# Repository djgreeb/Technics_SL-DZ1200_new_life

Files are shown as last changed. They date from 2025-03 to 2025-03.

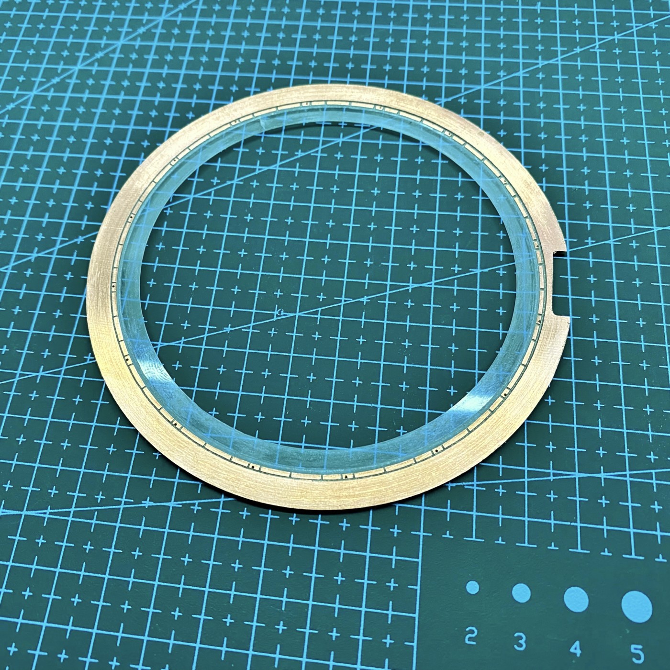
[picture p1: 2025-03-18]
Photo/IMG_2256.jpg

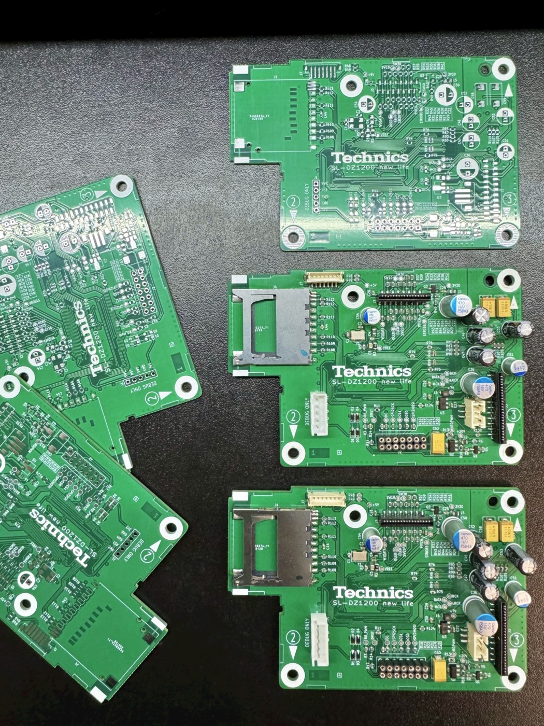
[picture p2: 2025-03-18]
Photo/IMG_4501.jpg

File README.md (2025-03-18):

# Technics_SL-DZ1200_new_life
 Technics, creating a new motherboard and display module.

This is a project to bring back to life the Technics SL-DZ1200 DJ player.

A new motherboard has been developed, based on the STM32F429 microcontroller. A new display module based on two OLED displays with a high frame refresh rate.

Added support for large capacity SD cards (64GB tested), support for playlists imported from Rekordbox, playback of wav files 16bit 44.1kHz only.

Display static and dynamic waveform, 8 hotspots, loop, slip loop, beat jump.

Digital SPDIF output is supported.

In addition to replacing the motherboard, it is necessary to modify the control panel boards and replace the display module.

Technics SL-DZ1200 new life. Comparison of sound and construction with the original deck:

https://youtu.be/YNCWHuYRNV8?si=jEZ1Wb_wVn2iVH1T

Other videos:

https://youtube.com/shorts/xwd6WtisLp0?si=1c5YiPtq2MnMOLq1

https://youtube.com/shorts/Ao05V8m91X4?si=t5FqrDS9XYP-LJhe

https://youtube.com/shorts/iWsxXxv2L6M?si=lasyaPYv3nFeNMoB

https://youtube.com/shorts/TOsjFpwztxs?si=jLOTwwjx0vi9ndan

    //	ver. 0.10
    //		- 64MB SDRAM
    //		- 2 OLED displays
    // 		- added scratch track
    //	ver. 0.21
    //		- project ported to new pcb
    //		- configured to work with the new DAC and SPDIF transmitter
    //		- most peripherals initialized
    //	ver. 0.23
    //		- most peripherals initialized
    //	ver. 0.25
    //		- TIM8 bug fixed. Missing a line: HAL_TIM_OnePulse_Init(&htim8, TIM_OPMODE_SINGLE) != HAL_OK)
    //	ver. 0.26
    //		- minor fixes
    //	ver. 0.27
    //		- split into separate *.h files
    //		- oled driver optimization
    //	ver. 0.31
    //		- added uart
    //		- added rgb leds function
    //		- added HD74HC164P LEDs
    //		- oled driver optimization
    //		- unused libraries cleaned up
    //	ver. 0.32
    //		- added adc process
    //		- TIM1 change config 333Hz->10KHz
    //	ver. 0.33
    //		- changed OLDEs configuration
    //		- added uart commands
    //		- LEDS_LOAD prc for HD74HC164P moved to audio handler 
    //	ver. 0.34
    //		- TIM1 change config 10KHz->3333Hz
    //		- added buttons prc
    //	ver. 0.35
    //		- minor fixes
    //	ver. 0.36
    //		- change motor GPIO initial state
    //	ver. 0.37
    //		- minor fixes
    //	ver. 0.38
    //		- add WFORMDYNAMIC reading prc
    //	ver. 0.41
    //		- minor fixes
    //	ver. 0.42
    //		- added rekordbox parser
    //	ver. 0.43
    //		- add blinking pads
    //	ver. 0.44
    //		- minor fixes
    //	ver. 0.47
    //		- added test sdram
    //		- added uart status messages
    //	ver. 0.49
    //		- added support use_lfn in fatfs
    //		- minor fixes
    //	ver. 0.51
    //		- improved SDRAM test
    //		- added fw version register to main.c
    //	ver. 0.53
    //		- minor fixes
    //		- changed the size of the heap and stack by 2X. Now Stack_Size 0x1000; Heap_Size 0x800;
    //	ver. 0.57
    //		- improved OLED library
    //		- rekordbox parser optimized
    //	ver. 0.61
    //		- improved OLED library
    //		- improved track loading process
    //	ver. 0.63
    //		- added optimization waveforms with color coefficient
    //	ver. 0.67
    //		- rekordbox parser improved
    //	ver. 0.68
    //		- fixed drawing of static waveform
    //	ver. 0.69
    //		- minor fixes
    //	ver. 0.70
    //		- CDJ900 font added
    //		- minor fixes
    //		- added pitch calculation
    //	ver. 0.71
    //		- added gui_generation.h
    //	ver. 0.74
    //		- minor fixes
    //	ver. 0.77
    //		- improved DrawMinuteMarkers()
    //		- added ShowTempo()
    //	ver. 0.81
    //		- removed initialization of SDRAM area from the scatter file, which significantly speeded up system startup
    //		- added mini sdram test
    //		- added ShowBPM()
    //	ver. 0.85
    //		- changed SDRAM parameter SdramTiming.WriteRecoveryTime = 4;			//2	//4 
    //		- changed adc pitch aproximation
    //		- added adc pitch hysteresis 
    //		- added DDM speed regulation
    //		- changed audio resampling coeff: optimal 32x, 4-point, 3rd-order optimal
    //		- improved and optimized audio resampling algorithm
    //	ver. 0.87
    //		- regenerated code in CubeMX
    //		- added encoder and timecode handlers
    //	ver. 0.89
    //		- added timecode encoder in code handler
    //	ver. 0.90
    //		- minor fixes
    //	ver. 0.92
    //		- fixed oled ram select
    //	ver. 0.93
    //		- added ROOT DISPLAY
    //	ver. 0.97
    //		- improved BORWSER functions
    //	ver. 0.98
    //		- added SD cars remove-insert handler
    //	ver. 0.99 
    //		- improved OLED_Putc function for outputting cut characters
    //	ver. 1.00 
    //		- fixed gui bug
    //	ver. 1.03 
    //		- fixed gui bug (increased size Stack_Size 0x1000, Heap_Size 0x800)
    //		- improved waveform code
    //	ver. 1.05
    //		- FontCDJ900 minor fixes
    //		- improved gui
    //		- added SD card symbol 
    //	ver. 1.07
    //		- added beatjump with calculate jump distantion
    //		- added hot cues a, b, c
    //	ver. 1.11
    //		- improved gui 
    //		- add browser animation
    //		- add 8 HOT CUES and PADS color from *.EXT file

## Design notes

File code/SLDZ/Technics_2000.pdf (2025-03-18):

## Technics_2000 Project Configuration Report

# 1. Description

## 1.1. Project

Project Name | Technics_2000
Board Name | Technics_2000
Generated with: | STM32CubeMX 4.22.0
Date | 04/03/2024

## 1.2. MCU

MCU Series | STM32F4
MCU Line | STM32F429/439
MCU name | STM32F429ZITx
MCU Package | LQFP144
MCU Pin number | 144

# 2. Pinout Configuration

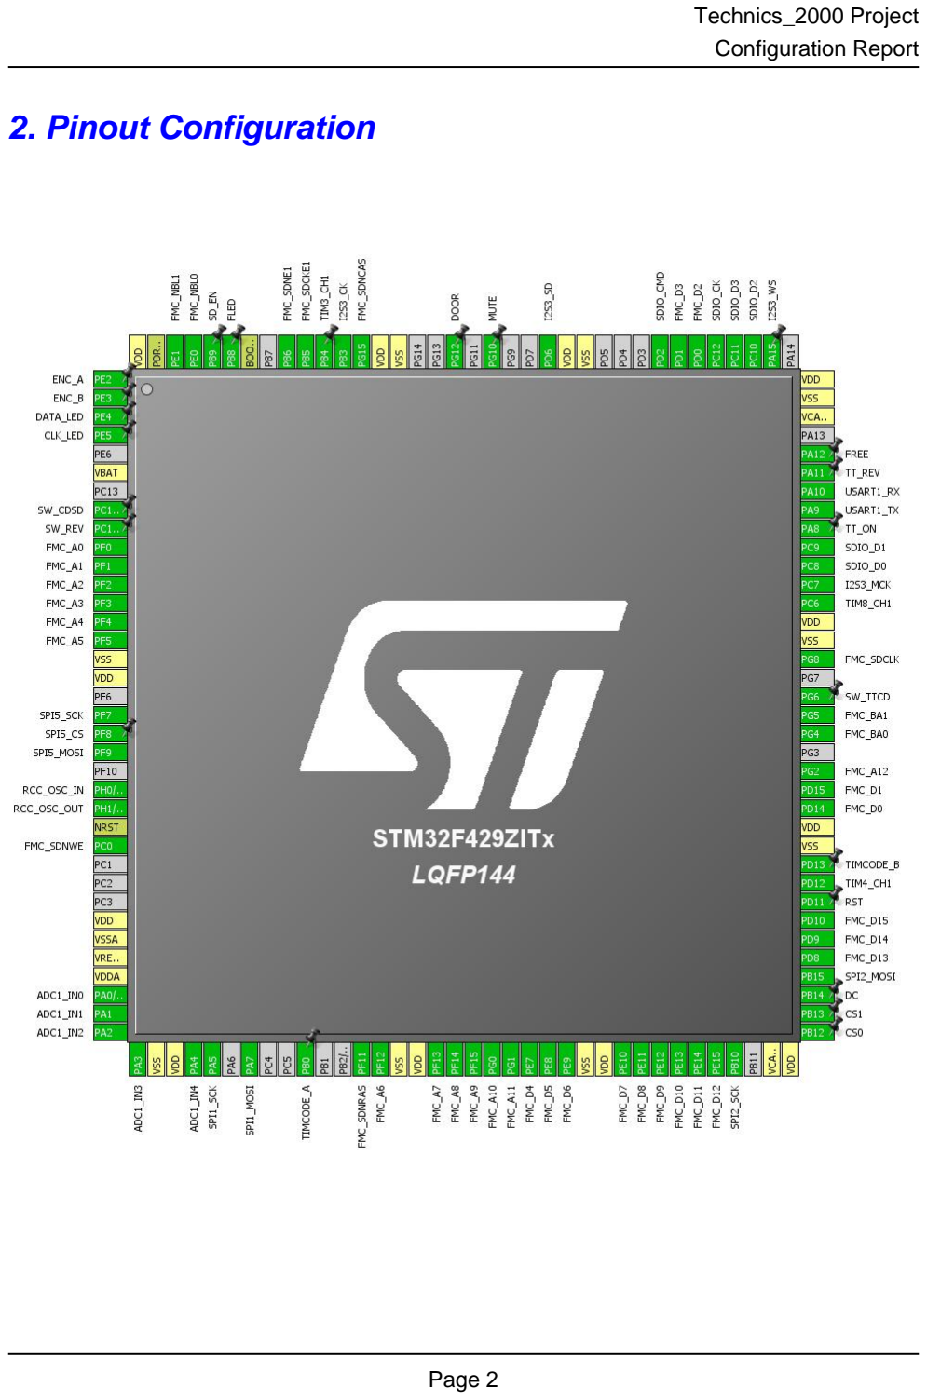
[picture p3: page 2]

# 3. Pins Configuration

Pin Number LQFP144 | Pin Name (function after reset) | Pin Type | Alternate Function(s) | Label
1 | PE2 | I/O | GPIO_EXTI2 | ENC_A
2 | PE3 * | I/O | GPIO_Input | ENC_B
3 | PE4 * | I/O | GPIO_Output | DATA_LED
4 | PE5 * | I/O | GPIO_Output | CLK_LED
6 | VBAT | Power
8 | PC14/OSC32_IN * | I/O | GPIO_Input | SW_CDSD
9 | PC15/OSC32_OUT * | I/O | GPIO_Input | SW_REV
10 | PF0 | I/O | FMC_A0
11 | PF1 | I/O | FMC_A1
12 | PF2 | I/O | FMC_A2
13 | PF3 | I/O | FMC_A3
14 | PF4 | I/O | FMC_A4
15 | PF5 | I/O | FMC_A5
16 | VSS | Power
17 | VDD | Power
19 | PF7 | I/O | SPI5_SCK
20 | PF8 * | I/O | GPIO_Output | SPI5_CS
21 | PF9 | I/O | SPI5_MOSI
23 | PH0/OSC_IN | I/O | RCC_OSC_IN
24 | PH1/OSC_OUT | I/O | RCC_OSC_OUT
25 | NRST | Reset
26 | PC0 | I/O | FMC_SDNWE
30 | VDD | Power
31 | VSSA | Power
32 | VREF+ | Power
33 | VDDA | Power
34 | PA0/WKUP | I/O | ADC1_IN0
35 | PA1 | I/O | ADC1_IN1
36 | PA2 | I/O | ADC1_IN2
37 | PA3 | I/O | ADC1_IN3
38 | VSS | Power
39 | VDD | Power
40 | PA4 | I/O | ADC1_IN4
41 | PA5 | I/O | SPI1_SCK
43 | PA7 | I/O | SPI1_MOSI
46 | PB0 | I/O | GPIO_EXTI0 | TIMCODE_A

Pin Number LQFP144 | Pin Name (function after reset) | Pin Type | Alternate Function(s) | Label
49 | PF11 | I/O | FMC_SDNRAS
50 | PF12 | I/O | FMC_A6
51 | VSS | Power
52 | VDD | Power
53 | PF13 | I/O | FMC_A7
54 | PF14 | I/O | FMC_A8
55 | PF15 | I/O | FMC_A9
56 | PG0 | I/O | FMC_A10
57 | PG1 | I/O | FMC_A11
58 | PE7 | I/O | FMC_D4
59 | PE8 | I/O | FMC_D5
60 | PE9 | I/O | FMC_D6
61 | VSS | Power
62 | VDD | Power
63 | PE10 | I/O | FMC_D7
64 | PE11 | I/O | FMC_D8
65 | PE12 | I/O | FMC_D9
66 | PE13 | I/O | FMC_D10
67 | PE14 | I/O | FMC_D11
68 | PE15 | I/O | FMC_D12
69 | PB10 | I/O | SPI2_SCK
71 | VCAP_1 | Power
72 | VDD | Power
73 | PB12 * | I/O | GPIO_Output | CS0
74 | PB13 * | I/O | GPIO_Output | CS1
75 | PB14 * | I/O | GPIO_Output | DC
76 | PB15 | I/O | SPI2_MOSI
77 | PD8 | I/O | FMC_D13
78 | PD9 | I/O | FMC_D14
79 | PD10 | I/O | FMC_D15
80 | PD11 * | I/O | GPIO_Output | RST
81 | PD12 | I/O | TIM4_CH1
82 | PD13 * | I/O | GPIO_Input | TIMCODE_B
83 | VSS | Power
84 | VDD | Power
85 | PD14 | I/O | FMC_D0
86 | PD15 | I/O | FMC_D1
87 | PG2 | I/O | FMC_A12
89 | PG4 | I/O | FMC_BA0

Pin Number LQFP144 | Pin Name (function after reset) | Pin Type | Alternate Function(s) | Label
90 | PG5 | I/O | FMC_BA1
91 | PG6 * | I/O | GPIO_Input | SW_TTCD
93 | PG8 | I/O | FMC_SDCLK
94 | VSS | Power
95 | VDD | Power
96 | PC6 | I/O | TIM8_CH1
97 | PC7 | I/O | I2S3_MCK
98 | PC8 | I/O | SDIO_D0
99 | PC9 | I/O | SDIO_D1
100 | PA8 * | I/O | GPIO_Output | TT_ON
101 | PA9 | I/O | USART1_TX
102 | PA10 | I/O | USART1_RX
103 | PA11 * | I/O | GPIO_Output | TT_REV
104 | PA12 * | I/O | GPIO_Output | FREE
106 | VCAP_2 | Power
107 | VSS | Power
108 | VDD | Power
110 | PA15 | I/O | I2S3_WS
111 | PC10 | I/O | SDIO_D2
112 | PC11 | I/O | SDIO_D3
113 | PC12 | I/O | SDIO_CK
114 | PD0 | I/O | FMC_D2
115 | PD1 | I/O | FMC_D3
116 | PD2 | I/O | SDIO_CMD
120 | VSS | Power
121 | VDD | Power
122 | PD6 | I/O | I2S3_SD
125 | PG10 * | I/O | GPIO_Output | MUTE
127 | PG12 * | I/O | GPIO_Input | DOOR
130 | VSS | Power
131 | VDD | Power
132 | PG15 | I/O | FMC_SDNCAS
133 | PB3 | I/O | I2S3_CK
134 | PB4 | I/O | TIM3_CH1
135 | PB5 | I/O | FMC_SDCKE1
136 | PB6 | I/O | FMC_SDNE1
138 | BOOT0 | Boot
139 | PB8 * | I/O | GPIO_Output | FLED
140 | PB9 * | I/O | GPIO_Input | SD_EN

Pin Number LQFP144 | Pin Name (function after reset) | Pin Type | Alternate Function(s) | Label
141 | PE0 | I/O | FMC_NBL0
142 | PE1 | I/O | FMC_NBL1
143 | PDR_ON | Reset
144 | VDD | Power

## * The pin is affected with an I/O function

# 4. Clock Tree Configuration

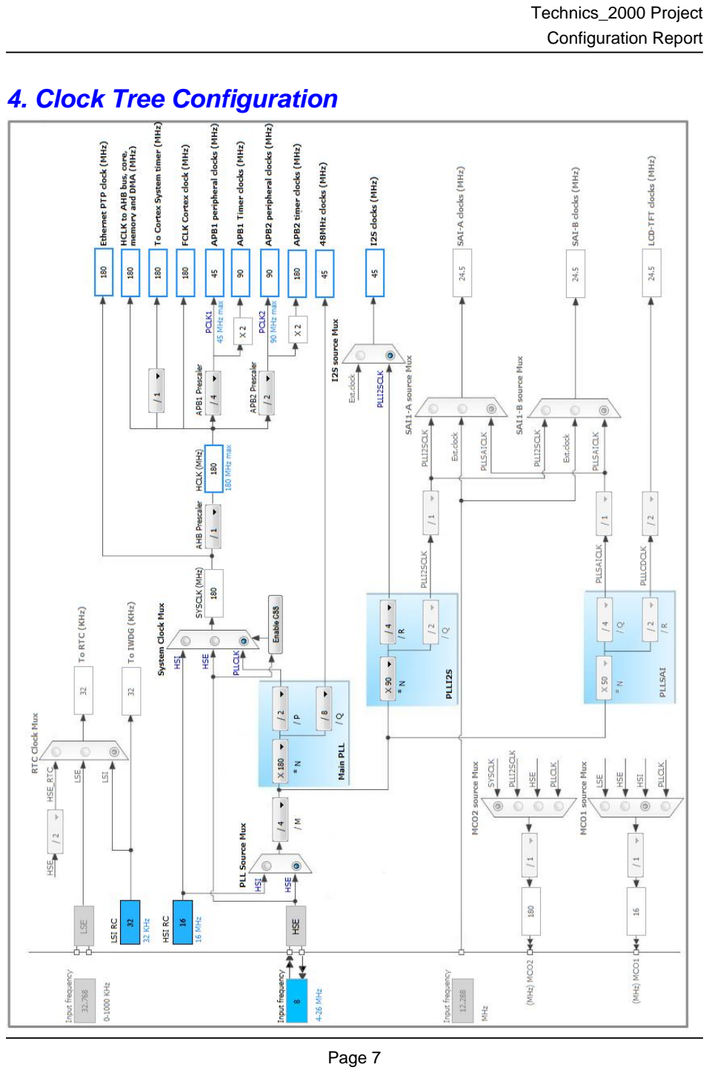
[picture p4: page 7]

# 5. IPs and Middleware Configuration

# 5.1. ADC1

## mode: IN0 mode: IN1 mode: IN2 mode: IN3 mode: IN4

## 5.1.1. Parameter Settings:

### ADCs_Common_Settings:

Mode | Independent mode

### ADC_Settings:

Clock Prescaler | PCLK2 divided by 4
Resolution | 12 bits (15 ADC Clock cycles)
Data Alignment | Right alignment
Scan Conversion Mode | Disabled
Continuous Conversion Mode | Disabled
Discontinuous Conversion Mode | Disabled
DMA Continuous Requests | Disabled
End Of Conversion Selection | EOC flag at the end of single channel conversion

### ADC_Regular_ConversionMode:

Number Of Conversion | 1
External Trigger Conversion Source | Regular Conversion launched by software
External Trigger Conversion Edge | None
Rank | 1
Channel | Channel 0
Sampling Time | 3 Cycles

### ADC_Injected_ConversionMode:

Number Of Conversions | 0

### WatchDog:

Enable Analog WatchDog Mode | false

# 5.2. FMC

## SDRAM 1

## Clock and chip enable: SDCKE1+SDNE1 Internal bank number: 4 banks Address: 13 bits Data: 16 bits Byte enable: set

## 5.2.1. SDRAM 1:

### SDRAM control:

Bank | SDRAM bank 2
Number of column address bits | 10 bits *
Number of row address bits | 13 bits
CAS latency | 3 memory clock cycles *
Write protection | Disabled
SDRAM common clock | 2 HCLK clock cycles *
SDRAM common burst read | Disabled
SDRAM common read pipe delay | 1 HCLK clock cycle *

### SDRAM timing in memory clock cycles:

Load mode register to active delay | 2 *
Exit self-refresh delay | 7 *
Self-refresh time | 4 *
SDRAM common row cycle delay | 7 *
Write recovery time | 4 *
SDRAM common row precharge delay | 2 *
Row to column delay | 2 *

# 5.3. I2S3

## Mode: Half-Duplex Master mode: Master Clock Output

## 5.3.1. Parameter Settings:

### Generic Parameters:

Transmission Mode | Mode Master Transmit
Communication Standard

| LSB First (Right Justified) *
Data and Frame Format | 16 Bits Data on 32 Bits Frame *
Selected Audio Frequency | 44 KHz *
Real Audio Frequency | 43.945 KHz *
Error between Selected and Real | -0.12 % *

### Clock Parameters:

Clock Source | I2S PLL Clock
Clock Polarity | Low

# 5.4. RCC

## High Speed Clock (HSE): Crystal/Ceramic Resonator

## 5.4.1. Parameter Settings:

### System Parameters:

VDD voltage (V) | 3.3
Instruction Cache | Enabled
Prefetch Buffer | Enabled
Data Cache | Enabled
Flash Latency(WS) | 5 WS (6 CPU cycle)

### RCC Parameters:

HSI Calibration Value | 16
TIM Prescaler Selection | Disabled
HSE Startup Timout Value (ms) | 100
LSE Startup Timout Value (ms) | 5000

### Power Parameters:

Power Regulatror Voltage Scale | Power Regulator Voltage Scale 1
Power Over Drive | Enabled

# 5.5. SDIO

## Mode: SD 4 bits Wide bus

## 5.5.1. Parameter Settings:

### SDIO parameters:

SDIOCLK clock divide factor | 4 *

# 5.6. SPI1

## Mode: Transmit Only Master

## 5.6.1. Parameter Settings:

### Basic Parameters:

Frame Format | Motorola
Data Size | 8 Bits
First Bit | MSB First

### Clock Parameters:

Prescaler (for Baud Rate) | 32 *
Baud Rate | 2.8125 MBits/s *
Clock Polarity (CPOL) | Low
Clock Phase (CPHA) | 1 Edge

### Advanced Parameters:

CRC Calculation | Disabled
NSS Signal Type | Software

# 5.7. SPI2

## Mode: Transmit Only Master

## 5.7.1. Parameter Settings:

### Basic Parameters:

Frame Format | Motorola
Data Size | 8 Bits
First Bit | MSB First

### Clock Parameters:

Prescaler (for Baud Rate) | 8 *
Baud Rate | 5.625 MBits/s *
Clock Polarity (CPOL) | Low
Clock Phase (CPHA) | 1 Edge

### Advanced Parameters:

CRC Calculation | Disabled
NSS Signal Type | Software

# 5.8. SPI5

## Mode: Transmit Only Master

## 5.8.1. Parameter Settings:

### Basic Parameters:

Frame Format | Motorola
Data Size | 8 Bits
First Bit | MSB First

### Clock Parameters:

Prescaler (for Baud Rate) | 64 *
Baud Rate | 1.40625 MBits/s *
Clock Polarity (CPOL) | Low
Clock Phase (CPHA) | 1 Edge

### Advanced Parameters:

CRC Calculation | Disabled
NSS Signal Type | Software

# 5.9. SYS

## Timebase Source: SysTick

# 5.10. TIM1

## Clock Source : Internal Clock

## 5.10.1. Parameter Settings:

### Counter Settings:

Prescaler (PSC - 16 bits value) | 299 *
Counter Mode | Up
Counter Period (AutoReload Register - 16 bits value ) | 179 *
Internal Clock Division (CKD) | Division by 4 *
Repetition Counter (RCR - 8 bits value) | 0

### Trigger Output (TRGO) Parameters:

Master/Slave Mode | Disable (no sync between this TIM (Master) and its Slaves

Trigger Event Selection | Reset (UG bit from TIMx_EGR)

# 5.11. TIM2

## Clock Source : Internal Clock

## 5.11.1. Parameter Settings:

### Counter Settings:

Prescaler (PSC - 16 bits value) | 89 *
Counter Mode | Up
Counter Period (AutoReload Register - 32 bits value ) | 0xFFFFFFFF *
Internal Clock Division (CKD) | Division by 4 *

### Trigger Output (TRGO) Parameters:

Master/Slave Mode | Disable (no sync between this TIM (Master) and its Slaves
Trigger Event Selection | Reset (UG bit from TIMx_EGR)

# 5.12. TIM3

## Clock Source : Internal Clock Channel1: PWM Generation CH1

## 5.12.1. Parameter Settings:

### Counter Settings:

Prescaler (PSC - 16 bits value) | 359 *
Counter Mode | Up
Counter Period (AutoReload Register - 16 bits value ) | 1024 *
Internal Clock Division (CKD) | Division by 4 *

### Trigger Output (TRGO) Parameters:

Master/Slave Mode | Disable (no sync between this TIM (Master) and its Slaves
Trigger Event Selection | Reset (UG bit from TIMx_EGR)

### PWM Generation Channel 1:

Mode | PWM mode 1
Pulse (16 bits value) | 10 *
Fast Mode | Disable
CH Polarity | High

# 5.13. TIM4

## Clock Source : Internal Clock Channel1: PWM Generation CH1

## 5.13.1. Parameter Settings:

### Counter Settings:

Prescaler (PSC - 16 bits value) | 89 *
Counter Mode | Up
Counter Period (AutoReload Register - 16 bits value ) | 12499 *
Internal Clock Division (CKD) | No Division

### Trigger Output (TRGO) Parameters:

Master/Slave Mode | Disable (no sync between this TIM (Master) and its Slaves
Trigger Event Selection | Reset (UG bit from TIMx_EGR)

### PWM Generation Channel 1:

Mode | PWM mode 1
Pulse (16 bits value) | 2500 *
Fast Mode | Disable
CH Polarity | High

# 5.14. TIM7

## mode: Activated

## 5.14.1. Parameter Settings:

### Counter Settings:

Prescaler (PSC - 16 bits value) | 16483 *
Counter Mode | Up
Counter Period (AutoReload Register - 16 bits value ) | 1 *

### Trigger Output (TRGO) Parameters:

Trigger Event Selection | Reset (UG bit from TIMx_EGR)

# 5.15. TIM8

## Clock Source : Internal Clock Channel1: PWM Generation CH1

## 5.15.1. Parameter Settings:

### Counter Settings:

Prescaler (PSC - 16 bits value) | 179 *
Counter Mode | Up
Counter Period (AutoReload Register - 16 bits value ) | 1 *
Internal Clock Division (CKD) | No Division
Repetition Counter (RCR - 8 bits value) | 95 *

### Trigger Output (TRGO) Parameters:

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

### Break And Dead Time management - BRK Configuration:

BRK State | Disable
BRK Polarity | High

### Break And Dead Time management - Output Configuration:

Automatic Output State | Disable
Off State Selection for Run Mode (OSSR) | Disable
Off State Selection for Idle Mode (OSSI) | Disable
Lock Configuration | Off

### PWM Generation Channel 1:

Mode | PWM mode 1
Pulse (16 bits value) | 1 *
Fast Mode | Disable
CH Polarity | Low *
CH Idle State | Reset

# 5.16. USART1

## Mode: Asynchronous

## 5.16.1. Parameter Settings:

### Basic Parameters:

Baud Rate | 115200

Word Length | 8 Bits (including Parity)
Parity | None
Stop Bits | 1

### Advanced Parameters:

Data Direction | Receive and Transmit
Over Sampling | 16 Samples

# 5.17. FATFS

## mode: SD Card

## 5.17.1. Set Defines:

### Version:

FATFS version | R0.11

### Function Parameters:

FS_READONLY (Read-only mode) | Disabled
FS_MINIMIZE (Minimization level) | Disabled
USE_STRFUNC (String functions) | Enabled with LF -> CRLF conversion
USE_FIND (Find functions) | Disabled
USE_MKFS (Make filesystem function) | Enabled
USE_FASTSEEK (Fast seek function) | Enabled
USE_LABEL (Volume label functions) | Disabled
USE_FORWARD (Forward function) | Disabled

### Locale and Namespace Parameters:

CODE_PAGE (Code page on target) | Multilingual Latin 1 (OEM)
USE_LFN (Use Long Filename) | Disabled
MAX_LFN (Max Long Filename) | 255
LFN_UNICODE (Enable Unicode) | ANSI/OEM
STRF_ENCODE (Character encoding) | UTF-8
FS_RPATH (Relative Path) | Disabled

### Physical Drive Parameters:

VOLUMES (Logical drives) | 1
MAX_SS (Maximum Sector Size) | 512
MIN_SS (Minimum Sector Size) | 512
MULTI_PARTITION (Volume partitions feature) | Disabled
USE_TRIM (Erase feature) | Disabled
FS_NOFSINFO (Force full FAT scan) | 0

### System Parameters:

FS_TINY (Tiny mode) | Disabled

FS_NORTC (Timestamp feature) | Dynamic timestamp
NORTC_YEAR (Year for timestamp) | 2015
NORTC_MON (Month for timestamp) | 6
NORTC_MDAY (Day for timestamp) | 4
WORD_ACCESS (Platform dependent access option) | Byte access
FS_REENTRANT (Re-Entrancy) | Disabled
FS_TIMEOUT (Timeout ticks) | 1000
SYNC_t (O/S sync object) | osSemaphoreId
FS_LOCK (Number of files opened simultaneously) | 2

## 5.17.2. IPs instances:

### SDIO/SDMMC:

SDIO instance | SDIO

### * User modified value

# 6. System Configuration

# 6.1. GPIO configuration

IP | Pin | Signal | GPIO mode | GPIO pull/up pull down

## Max Speed

## User Label

ADC1 | PA0/WKUP | ADC1_IN0 | Analog mode | No pull-up and no pull-down | n/a
| PA1 | ADC1_IN1 | Analog mode | No pull-up and no pull-down | n/a
| PA2 | ADC1_IN2 | Analog mode | No pull-up and no pull-down | n/a
| PA3 | ADC1_IN3 | Analog mode | No pull-up and no pull-down | n/a
| PA4 | ADC1_IN4 | Analog mode | No pull-up and no pull-down | n/a
FMC | PF0 | FMC_A0 | Alternate Function Push Pull | No pull-up and no pull-down | Very High
| PF1 | FMC_A1 | Alternate Function Push Pull | No pull-up and no pull-down | Very High
| PF2 | FMC_A2 | Alternate Function Push Pull | No pull-up and no pull-down | Very High
| PF3 | FMC_A3 | Alternate Function Push Pull | No pull-up and no pull-down | Very High
| PF4 | FMC_A4 | Alternate Function Push Pull | No pull-up and no pull-down | Very High
| PF5 | FMC_A5 | Alternate Function Push Pull | No pull-up and no pull-down | Very High
PC0 | FMC_SDNWE Alternate Function Push Pull | No pull-up and no pull-down | Very High
PF11 | FMC_SDNRAS Alternate Function Push Pull | No pull-up and no pull-down | Very High
| PF12 | FMC_A6 | Alternate Function Push Pull | No pull-up and no pull-down | Very High
| PF13 | FMC_A7 | Alternate Function Push Pull | No pull-up and no pull-down | Very High
| PF14 | FMC_A8 | Alternate Function Push Pull | No pull-up and no pull-down | Very High
| PF15 | FMC_A9 | Alternate Function Push Pull | No pull-up and no pull-down | Very High
| PG0 | FMC_A10 | Alternate Function Push Pull | No pull-up and no pull-down | Very High
| PG1 | FMC_A11 | Alternate Function Push Pull | No pull-up and no pull-down | Very High
| PE7 | FMC_D4 | Alternate Function Push Pull | No pull-up and no pull-down | Very High
| PE8 | FMC_D5 | Alternate Function Push Pull | No pull-up and no pull-down | Very High
| PE9 | FMC_D6 | Alternate Function Push Pull | No pull-up and no pull-down | Very High
| PE10 | FMC_D7 | Alternate Function Push Pull | No pull-up and no pull-down | Very High
| PE11 | FMC_D8 | Alternate Function Push Pull | No pull-up and no pull-down | Very High
| PE12 | FMC_D9 | Alternate Function Push Pull | No pull-up and no pull-down | Very High
| PE13 | FMC_D10 | Alternate Function Push Pull | No pull-up and no pull-down | Very High
| PE14 | FMC_D11 | Alternate Function Push Pull | No pull-up and no pull-down | Very High
| PE15 | FMC_D12 | Alternate Function Push Pull | No pull-up and no pull-down | Very High
| PD8 | FMC_D13 | Alternate Function Push Pull | No pull-up and no pull-down | Very High
| PD9 | FMC_D14 | Alternate Function Push Pull | No pull-up and no pull-down | Very High
| PD10 | FMC_D15 | Alternate Function Push Pull | No pull-up and no pull-down | Very High
| PD14 | FMC_D0 | Alternate Function Push Pull | No pull-up and no pull-down | Very High
| PD15 | FMC_D1 | Alternate Function Push Pull | No pull-up and no pull-down | Very High
| PG2 | FMC_A12 | Alternate Function Push Pull | No pull-up and no pull-down | Very High

IP | Pin | Signal | GPIO mode | GPIO pull/up pull down

## Max Speed

## User Label

| PG4 | FMC_BA0 | Alternate Function Push Pull | No pull-up and no pull-down | Very High
| PG5 | FMC_BA1 | Alternate Function Push Pull | No pull-up and no pull-down | Very High
| PG8 | FMC_SDCLK | Alternate Function Push Pull | No pull-up and no pull-down | Very High
| PD0 | FMC_D2 | Alternate Function Push Pull | No pull-up and no pull-down | Very High
| PD1 | FMC_D3 | Alternate Function Push Pull | No pull-up and no pull-down | Very High
PG15 | FMC_SDNCAS Alternate Function Push Pull | No pull-up and no pull-down | Very High
PB5 | FMC_SDCKE1 Alternate Function Push Pull | No pull-up and no pull-down | Very High
| PB6 | FMC_SDNE1 | Alternate Function Push Pull | No pull-up and no pull-down | Very High
| PE0 | FMC_NBL0 | Alternate Function Push Pull | No pull-up and no pull-down | Very High
| PE1 | FMC_NBL1 | Alternate Function Push Pull | No pull-up and no pull-down | Very High
I2S3 | PC7 | I2S3_MCK | Alternate Function Push Pull | No pull-up and no pull-down | Low
| PA15 | I2S3_WS | Alternate Function Push Pull | No pull-up and no pull-down | Low
| PD6 | I2S3_SD | Alternate Function Push Pull | No pull-up and no pull-down | Low
| PB3 | I2S3_CK | Alternate Function Push Pull | No pull-up and no pull-down | Low
RCC | PH0/OSC_I N | RCC_OSC_IN | n/a | n/a | n/a
| PH1/OSC_O UT | RCC_OSC_OUT | n/a | n/a | n/a
SDIO | PC8 | SDIO_D0 | Alternate Function Push Pull | No pull-up and no pull-down | Very High
| PC9 | SDIO_D1 | Alternate Function Push Pull | No pull-up and no pull-down | Very High
| PC10 | SDIO_D2 | Alternate Function Push Pull | No pull-up and no pull-down | Very High
| PC11 | SDIO_D3 | Alternate Function Push Pull | No pull-up and no pull-down | Very High
| PC12 | SDIO_CK | Alternate Function Push Pull | No pull-up and no pull-down | Very High
| PD2 | SDIO_CMD | Alternate Function Push Pull | No pull-up and no pull-down | Very High
SPI1 | PA5 | SPI1_SCK | Alternate Function Push Pull | No pull-up and no pull-down | Very High
*
| PA7 | SPI1_MOSI | Alternate Function Push Pull | No pull-up and no pull-down | Very High
*
SPI2 | PB10 | SPI2_SCK | Alternate Function Push Pull | No pull-up and no pull-down | Very High
*
| PB15 | SPI2_MOSI | Alternate Function Push Pull | No pull-up and no pull-down | Very High
*
SPI5 | PF7 | SPI5_SCK | Alternate Function Push Pull | No pull-up and no pull-down | Very High
*
| PF9 | SPI5_MOSI | Alternate Function Push Pull | No pull-up and no pull-down | Very High
*
TIM3 | PB4 | TIM3_CH1 | Alternate Function Push Pull | No pull-up and no pull-down | Low
TIM4 | PD12 | TIM4_CH1 | Alternate Function Push Pull | No pull-up and no pull-down | Low
TIM8 | PC6 | TIM8_CH1 | Alternate Function Push Pull | No pull-up and no pull-down | Low
USART1 | PA9 | USART1_TX | Alternate Function Push Pull | Pull-up

IP | Pin | Signal | GPIO mode | GPIO pull/up pull down | Max Speed | User Label
| | | | | Very High *
| PA10 | USART1_RX | Alternate Function Push Pull | Pull-up | Very High *
| | | Rising edge trigger detection | No pull-up and no pull-down | n/a | ENC_A
| PE3 | GPIO_Input | Input mode | No pull-up and no pull-down | n/a | ENC_B
| PE4 | GPIO_Output | Output Push Pull | No pull-up and no pull-down | Very High * | DATA_LED
| PE5 | GPIO_Output | Output Push Pull | No pull-up and no pull-down | Very High * | CLK_LED
| PC14/OSC3 2_IN | GPIO_Input | Input mode | No pull-up and no pull-down | n/a | SW_CDSD
| PC15/OSC3 2_OUT | GPIO_Input | Input mode | No pull-up and no pull-down | n/a | SW_REV
| PF8 | GPIO_Output | Output Push Pull | No pull-up and no pull-down | Medium * | SPI5_CS
| PB0 | GPIO_EXTI0 | External Interrupt Mode with Falling edge trigger detection | No pull-up and no pull-down | n/a | TIMCODE_A
| PB12 | GPIO_Output | Output Push Pull | No pull-up and no pull-down | Very High * | CS0
| PB13 | GPIO_Output | Output Push Pull | No pull-up and no pull-down | Very High * | CS1
| PB14 | GPIO_Output | Output Push Pull | No pull-up and no pull-down | Very High * | DC
| PD11 | GPIO_Output | Output Push Pull | No pull-up and no pull-down | Low | RST
| PD13 | GPIO_Input | Input mode | No pull-up and no pull-down | n/a | TIMCODE_B
| PG6 | GPIO_Input | Input mode | No pull-up and no pull-down | n/a | SW_TTCD
| PA8 | GPIO_Output | Output Push Pull | No pull-up and no pull-down | Medium * | TT_ON
| PA11 | GPIO_Output | Output Push Pull | No pull-up and no pull-down | Medium * | TT_REV
| PA12 | GPIO_Output | Output Push Pull | No pull-up and no pull-down | Medium * | FREE
| PG10 | GPIO_Output | Output Push Pull | No pull-up and no pull-down | Low | MUTE
| PG12 | GPIO_Input | Input mode | No pull-up and no pull-down | n/a | DOOR
| PB8 | GPIO_Output | Output Push Pull | No pull-up and no pull-down | Medium * | FLED
| PB9 | GPIO_Input | Input mode | No pull-up and no pull-down | n/a | SD_EN
GPIO | PE2 | GPIO_EXTI2 | External Interrupt Mode with

# 6.2. DMA configuration

DMA request | Stream | Direction | Priority
SPI1_TX | DMA2_Stream3 | Memory To Peripheral | Low

## SPI1_TX: DMA2_Stream3 DMA request Settings:

Mode: | Normal
Use fifo: | Disable
Peripheral Increment: | Disable
Memory Increment: | Enable *
Peripheral Data Width: | Byte
Memory Data Width: | Byte

# 6.3. NVIC configuration

Interrupt Table | Enable | Preenmption Priority | SubPriority
Non maskable interrupt | true | 0 | 0
Hard fault interrupt | true | 0 | 0
Memory management fault | true | 0 | 0
Pre-fetch fault, memory access fault | true | 0 | 0
Undefined instruction or illegal state | true | 0 | 0
System service call via SWI instruction | true | 0 | 0
Debug monitor | true | 0 | 0
Pendable request for system service | true | 0 | 0
System tick timer | true | 0 | 0
EXTI line0 interrupt | true | 2 | 0
EXTI line2 interrupt | true | 6 | 0
TIM1 update interrupt and TIM10 global interrupt | true | 5 | 0
USART1 global interrupt | true | 3 | 0
SPI3 global interrupt | true | 0 | 0
TIM7 global interrupt | true | 1 | 0
DMA2 stream3 global interrupt | true | 5 | 0
PVD interrupt through EXTI line 16 | unused
Flash global interrupt | unused
RCC global interrupt | unused
ADC1, ADC2 and ADC3 global interrupts | unused
TIM1 break interrupt and TIM9 global interrupt | unused
TIM1 trigger and commutation interrupts and TIM11 global interrupt | unused
TIM1 capture compare interrupt | unused
TIM2 global interrupt | unused
TIM3 global interrupt | unused
TIM4 global interrupt | unused
SPI1 global interrupt | unused
SPI2 global interrupt | unused
TIM8 break interrupt and TIM12 global interrupt | unused
TIM8 update interrupt and TIM13 global interrupt | unused
TIM8 trigger and commutation interrupts and TIM14 global interrupt | unused
TIM8 capture compare interrupt | unused
FMC global interrupt | unused
SDIO global interrupt | unused
FPU global interrupt | unused
SPI5 global interrupt | unused

### * User modified value

# 7. Power Consumption Calculator report

### 7.1. Microcontroller Selection

Series | STM32F4
Line | STM32F429/439
MCU | STM32F429ZITx
Datasheet | 024030_Rev8

### 7.2. Parameter Selection

Temperature | 25
Vdd | null

# 8. Software Project

## 8.1. Project Settings

Name | Value
Project Name | Technics_2000
Project Folder | C:\Keil_v5\My_Project\SLDZ
Toolchain / IDE | MDK-ARM V5
Firmware Package Name and Version | STM32Cube FW_F4 V1.16.0

## 8.2. Code Generation Settings

Name | Value
STM32Cube Firmware Library Package | Copy only the necessary library files
Generate peripheral initialization as a pair of '.c/.h' files | Yes
Backup previously generated files when re-generating | No
Delete previously generated files when not re-generated | No
Set all free pins as analog (to optimize the power consumption) | No

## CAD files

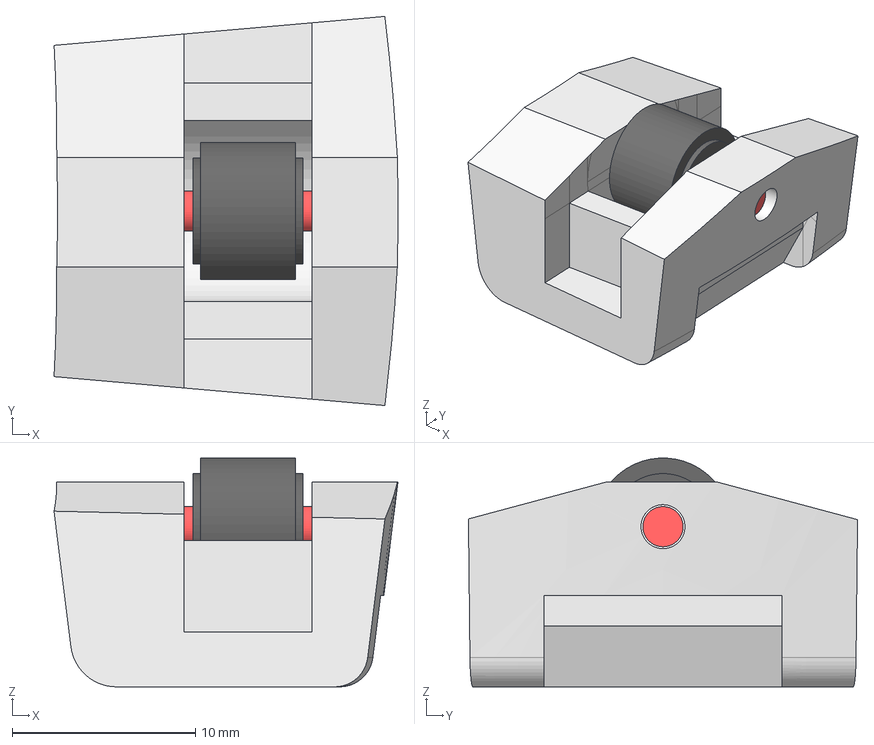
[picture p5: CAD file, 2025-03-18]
3D print/Roller Holder/Roller Holder.FCStd
18.8 x 21.3 x 12.5 mm
Roller001
Spindel

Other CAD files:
CNC/LEDS plexiglass/CUT.dwg

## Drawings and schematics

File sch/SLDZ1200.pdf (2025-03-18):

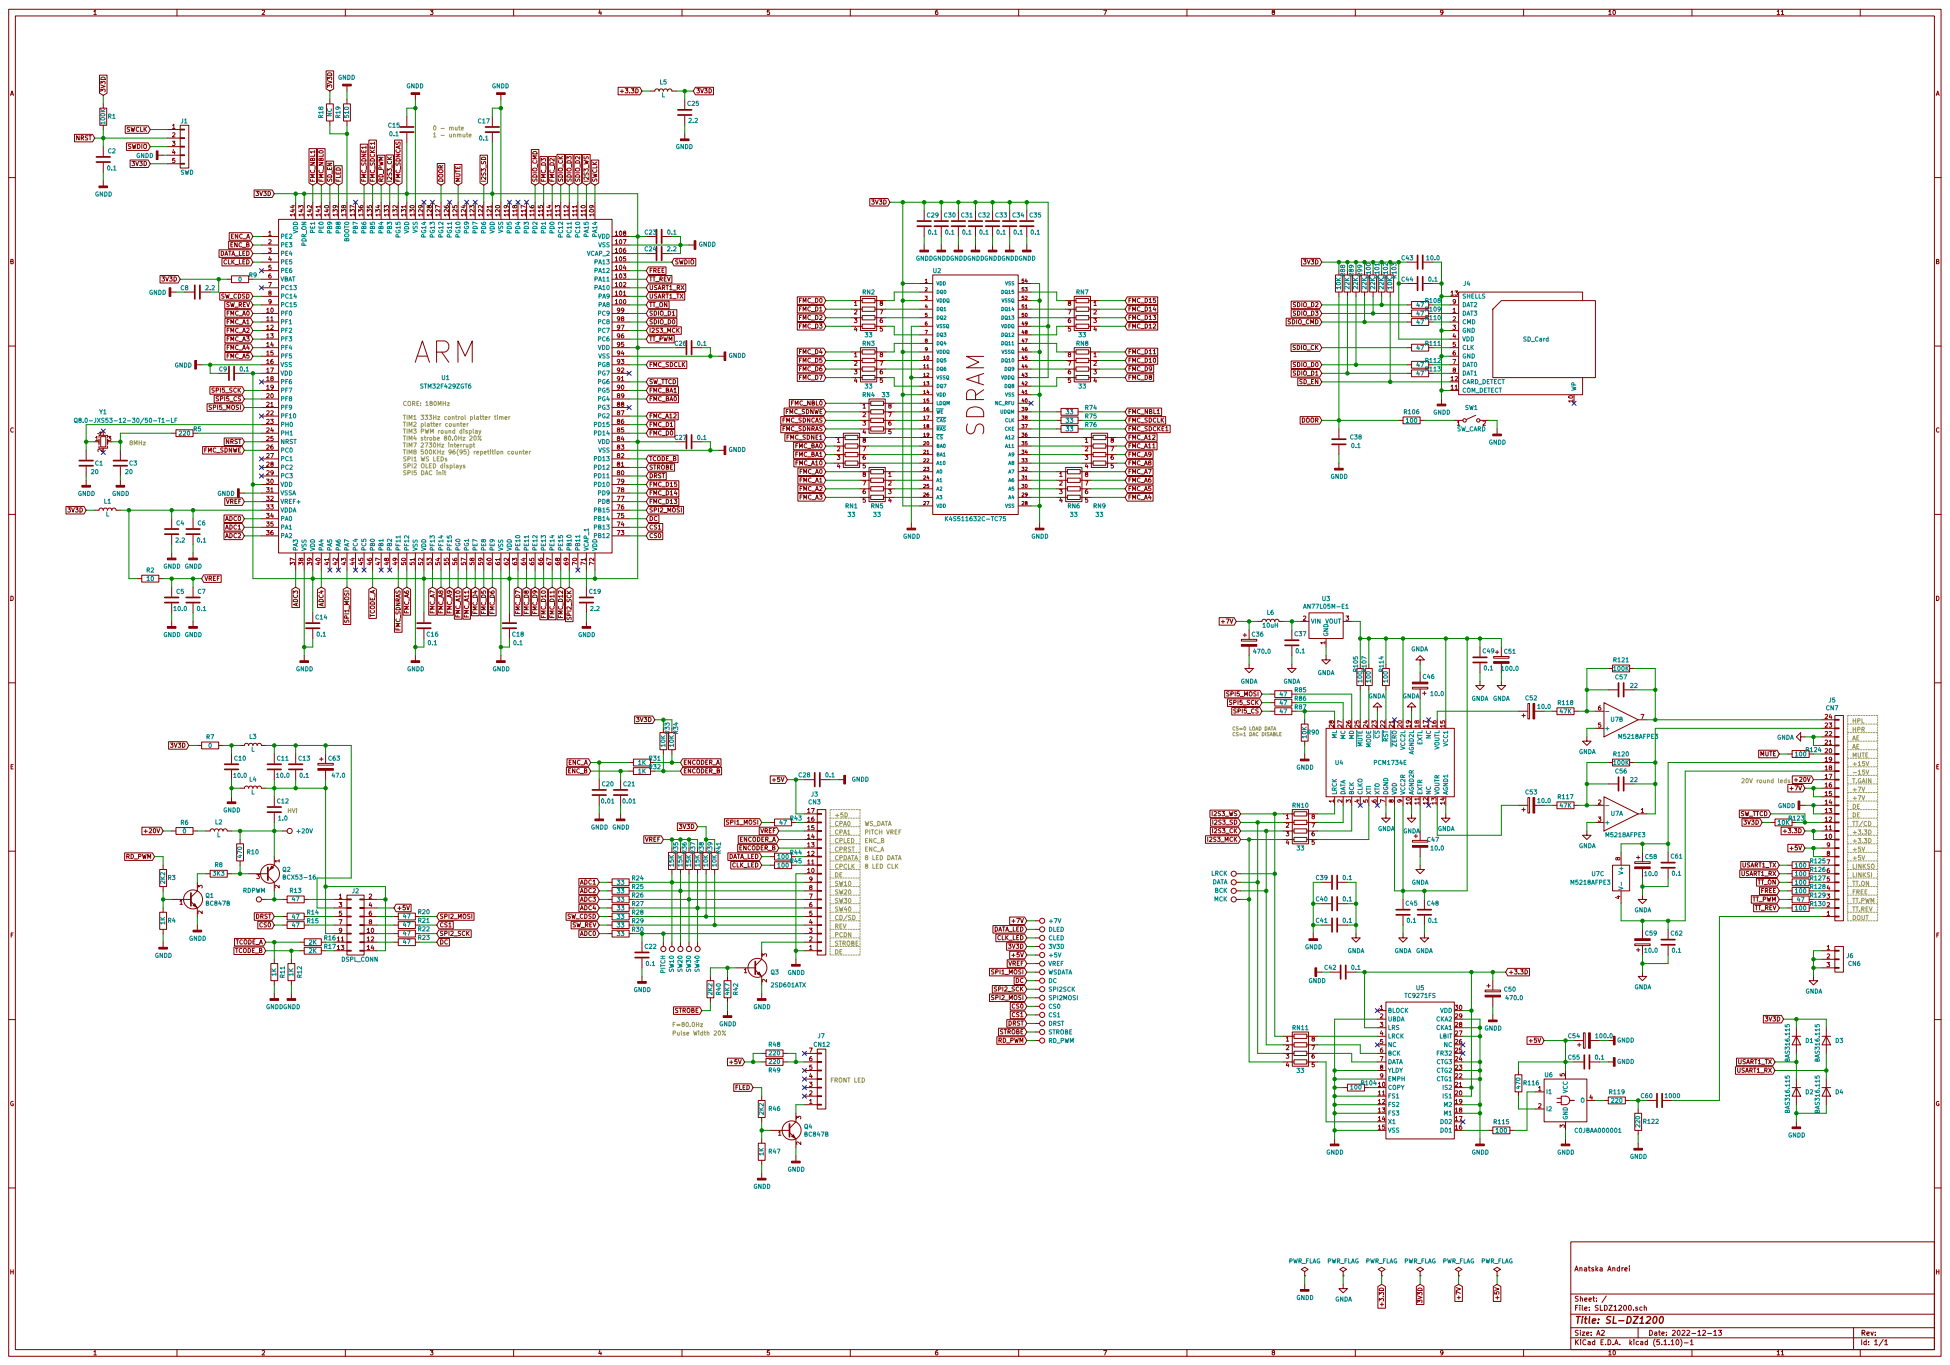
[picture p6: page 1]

CORE: 180MHz TIM1 333Hz control platter timer

TIM2 platter counter
TIM3 PWM round display TIM4 strobe 80.0Hz 20%

1 AGND2R 10 EXTR 11 NC 12 VOUTR 13 AGND1 14 VCC1 15 VOUTL 16 NC 17 EXTL 18 AGND2L 19 DATA

2 VCC2L 20 ZERO 21 RST 22 CS 23 MODE 24 MUTE 25 MD 26 MC 27 ML 28 BCK

File: SLDZ1200.sch Sheet: / Anatska Andrei

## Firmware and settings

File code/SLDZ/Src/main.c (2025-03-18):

/**
  ******************************************************************************
  * File Name          : main.c
  * Description        : Main program body
  ******************************************************************************
  * This notice applies to any and all portions of this file
  * that are not between comment pairs USER CODE BEGIN and
  * USER CODE END. Other portions of this file, whether 
  * inserted by the user or by software development tools
  * are owned by their respective copyright owners.
  *
  * Copyright (c) 2024 STMicroelectronics International N.V. 
  * All rights reserved.
  *
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
  ******************************************************************************
  */
/* Includes ------------------------------------------------------------------*/
#include "main.h"
#include "stm32f4xx_hal.h"
#include "adc.h"
#include "dma.h"
#include "fatfs.h"
#include "i2s.h"
#include "sdio.h"
#include "spi.h"
#include "tim.h"
#include "usart.h"
#include "gpio.h"
#include "fmc.h"

/* USER CODE BEGIN Includes */
#include <math.h>
#include "arm_math.h"
#include "stm32f4xx_ll_fmc.h"
#include "core_cm4.h"
#include <string.h>
/* Display part---------------------------------------------------------*/
#include "fonts.h"
#include "oled.h"



////////////////////////////////////////////////////////////////////////////////////////
//
//
//
//
//		Generated with: STM32CubeMX 4.22.0
//		Firmware Package Name and Version STM32Cube FW_F4 V1.16.0
//
//
//	arm_math.h add #define ARM_MATH_CM4	in 290 line
//	replace file fmc.c from copy __fmc.c
//	file stm32f4xx_it.c: delete - void SPI3_IRQHandler(void)
//	replace file stm32f4xx_hal_spi.c from copy __stm32f4xx_hal_spi.c
//	replace file tim.c (or add to TIM8)
//				if (HAL_TIM_OnePulse_Init(&htim8, TIM_OPMODE_SINGLE) != HAL_OK)
//				{
//					_Error_Handler(__FILE__, __LINE__);
//				}
//	
//
//
//
//
//	TIM1 3333Hz control platter timer (333Hz)
//	TIM2 platter counter
//	TIM3 PWM round display
//	TIM4 strobe 80.0Hz 20%
//	TIM7 2730Hz interrupt
//	TIM8 500KHz 96(95) repetition counter
//	SPI1 WS LEDs
//	SPI2 OLED displays
//	SPI5 DAC init
//
//
//
//
//
//
////////////////////////////////////////////////////////////////////////////////////////
//
//
//
//	ver. 0.10
//		- 64MB SDRAM
//		- 2 OLED displays
// 		- added scratch track
//	ver. 0.21
//		- project ported to new pcb
//		- configured to work with the new DAC and SPDIF transmitter
//		- most peripherals initialized
//	ver. 0.23
//		- most peripherals initialized
//	ver. 0.25
//		- TIM8 bug fixed. Missing a line: HAL_TIM_OnePulse_Init(&htim8, TIM_OPMODE_SINGLE) != HAL_OK)
//	ver. 0.26
//		- minor fixes
//	ver. 0.27
//		- split into separate *.h files
//		- oled driver optimization
//	ver. 0.31
//		- added uart
//		- added rgb leds function
//		- added HD74HC164P LEDs
//		- oled driver optimization
//		- unused libraries cleaned up
//	ver. 0.32
//		- added adc process
//		- TIM1 change config 333Hz->10KHz
//	ver. 0.33
//		- changed OLDEs configuration
//		- added uart commands
//		- LEDS_LOAD prc for HD74HC164P moved to audio handler 
//	ver. 0.34
//		- TIM1 change config 10KHz->3333Hz
//		- added buttons prc
//	ver. 0.35
//		- minor fixes
//	ver. 0.36
//		- change motor GPIO initial state
//	ver. 0.37
//		- minor fixes
//	ver. 0.38
//		- add WFORMDYNAMIC reading prc
//	ver. 0.41
//		- minor fixes
//	ver. 0.42
//		- added rekordbox parser
//	ver. 0.43
//		-	add blinking pads
//	ver. 0.44
//		- minor fixes
//	ver. 0.47
//		-	added test sdram
//		-	added uart status messages
//	ver. 0.49
//		-	added support use_lfn in fatfs
//		- minor fixes
//	ver. 0.51
//		- improved SDRAM test
//		-	added fw version register to main.c
//	ver. 0.53
//		- minor fixes
//		-	changed the size of the heap and stack by 2X. Now Stack_Size 0x1000; Heap_Size 0x800;
//	ver. 0.57
//		-	improved OLED library
//		- rekordbox parser optimized
//	ver. 0.61
//		-	improved OLED library
//		-	improved track loading process
//	ver. 0.63
//		-	added optimization waveforms with color coefficient
//	ver. 0.67
//		- rekordbox parser improved
//	ver. 0.68
//		-	fixed drawing of static waveform
//	ver. 0.69
//		- minor fixes
//	ver. 0.70
//		- CDJ900 font added
//		- minor fixes
//		- added pitch calculation
//	ver. 0.71
//		- added gui_generation.h
//	ver. 0.74
//		- minor fixes
//	ver. 0.77
//		-	improved DrawMinuteMarkers()
//		- added ShowTempo()
//	ver. 0.81
//		- removed initialization of SDRAM area from the scatter file, which significantly speeded up system startup
//		-	added mini sdram test
//		- added ShowBPM()
//	ver. 0.85
//		- changed SDRAM parameter SdramTiming.WriteRecoveryTime = 4;			//2	//4 
//		- changed adc pitch aproximation
//		- added adc pitch hysteresis 
//		- added DDM speed regulation
//		- changed audio resampling coeff: optimal 32x, 4-point, 3rd-order optimal
//		- improved and optimized audio resampling algorithm
//	ver. 0.87
//		- regenerated code in CubeMX
//		- added encoder and timecode handlers
//	ver. 0.89
//		-	added timecode encoder in code handler
//	ver. 0.90
//		- minor fixes
//	ver. 0.92
//		- fixed oled ram select
//	ver. 0.93
//		-	added ROOT DISPLAY
//	ver. 0.97
//		- improved BORWSER functions
//	ver. 0.98
//		-	added SD cars remove-insert handler
//	ver. 0.99 
//		-	improved OLED_Putc function for outputting cut characters
//	ver. 1.00 
//		- fixed gui bug
//	ver. 1.03 
//		- fixed gui bug (increased size Stack_Size 0x1000, Heap_Size 0x800)
//		- improved waveform code
//	ver. 1.05
//		-	FontCDJ900 minor fixes
//		-	improved gui
//		-	added SD card symbol 
//	ver. 1.07
//		-	added beatjump with calculate jump distantion
//		-	added hot cues a, b, c
//	ver. 1.11
//		-	improved gui 
//		-	add browser animation
//		-	add 8 HOT CUES and PADS color from *.EXT file
//
//////////////////////////////////////////////////////////////////////////////////////////////////////////////



/* USER CODE END Includes */


/* USER CODE BEGIN PV */
extern uint8_t OLED_RAM_SELECT;
#include "global_variables.h"
extern uint8_t OLED_BUF[2][1024];				//0-HIGH DISPLAY (BROWSE) 1-LOW DISPLAY (WAVEFORM)
#include "gui_generation.h"
#include "rekordbox.h"

static char FW_VERSION[4] = "1.11";	

/* USER CODE END PV */

void SystemClock_Config(void);

/* USER CODE BEGIN PFP */
void GET_SD_INFO(void);								//check used and free memory on sd card
void COLOR_SET(uint32_t color, uint8_t LD);			//	set color buffer for rgb leds	
void ADC_SELECT_CH(uint32_t ch);				//		select channel for ADC	
void BLINK_INTERFACE(uint8_t pd);				//blinking pads and round display - reaction
void CLEAR_DB_VARIABLES(void);


/* USER CODE END PFP */

/* USER CODE BEGIN 0 */
#include "audio_handler.h"
#include "dac.h"



/* USER CODE END 0 */

int main(void)
{

  /* MCU Configuration----------------------------------------------------------*/

  /* Reset of all peripherals, Initializes the Flash interface and the Systick. */
  HAL_Init();

  /* Configure the system clock */
  SystemClock_Config();

  /* Initialize all configured peripherals */
  MX_GPIO_Init();
  MX_DMA_Init();
  MX_SDIO_SD_Init();
  MX_FATFS_Init();
  MX_FMC_Init();
  MX_I2S3_Init();
  MX_SPI2_Init();
  MX_TIM1_Init();
  MX_TIM2_Init();
  MX_TIM3_Init();
  MX_ADC1_Init();
  MX_SPI5_Init();
  MX_SPI1_Init();
  MX_TIM4_Init();
  MX_TIM8_Init();
  MX_USART1_UART_Init();
  MX_TIM7_Init();

  /* USER CODE BEGIN 2 */
	MOTOR_FREE_ON;
	USART1->CR1 |= USART_CR1_RXNEIE; //interrupt for a RX enable
	HAL_GPIO_WritePin(RST_GPIO_Port, RST_Pin, GPIO_PIN_SET);
	#if defined(USART_STATUS_SENDER)		
	sprintf((char*)U_TX_DATA, "%s", "Start system\n\r");	
	HAL_UART_Transmit(&huart1, U_TX_DATA, 14, 5);	
	sprintf((char*)U_TX_DATA, "%s", "FW ver. ");	
	HAL_UART_Transmit(&huart1, U_TX_DATA, 8, 5);	
	HAL_UART_Transmit(&huart1, FW_VERSION, 4, 5);	
	sprintf((char*)U_TX_DATA, "%s", "\n\r");	
	HAL_UART_Transmit(&huart1, U_TX_DATA, 2, 5);	
	#endif	

	OLED_CS0;	
	HAL_Delay(1);
	OLED_00_Init();
	OLED_Set_Contrast(0);
	OLED_CS1;	
	HAL_Delay(1);
	OLED_01_Init();
	OLED_Set_Contrast(0);
	
	OLED_CS0;	
	OLED_RAM_SELECT = OLED_BROWSE;
	COPY_LOGO(0);							//DRAW STARTUP
	OLED_UpdateScreen();	
	OLED_CS1;	
	OLED_RAM_SELECT = OLED_WFM;
	COPY_LOGO(1);							//DRAW STARTUP
	OLED_UpdateScreen();		
	HAL_I2S_Transmit_IT(&hi2s3, PCM_2, 2);				//start audio process	
	#if defined(USART_STATUS_SENDER)		
	sprintf((char*)U_TX_DATA, "Start audio process\n\r");	
	HAL_UART_Transmit(&huart1, U_TX_DATA, 21, 5);	
	#endif	

	HAL_TIM_Base_Start_IT(&htim1);
	HAL_TIM_Base_Start_IT(&htim2);
	TIM3->CCR1 = 0;					//round PWM
	HAL_TIM_PWM_Start(&htim3, TIM_CHANNEL_1);		//PWM ROUND
	HAL_TIM_PWM_Start(&htim4, TIM_CHANNEL_1);		//PWM STROBE
	
	HAL_TIM_PWM_Start(&htim8, TIM_CHANNEL_1);		//start PWM for DDM	
	HAL_TIM_Base_Start_IT(&htim7);							//start timer+interrupt for DDM
	MOTOR_FREE_OFF;
	
	DAC_INIT();
	HAL_GPIO_WritePin(MUTE_GPIO_Port, MUTE_Pin, GPIO_PIN_SET);			//unmute
	#if defined(USART_STATUS_SENDER)		
	sprintf((char*)U_TX_DATA, "DAC init\n\r");	
	HAL_UART_Transmit(&huart1, U_TX_DATA, 10, 5);	
	#endif	
	
	LEDS_LOAD_CNT = 0;
	for(N=0;N<224;N++)
		{
		N+=N;	
		if(N>223)
			{
			N = 223;	
			}		
		OLED_CS1;
		HAL_Delay(20);	
		OLED_Set_Contrast(N);
		OLED_CS0;
		HAL_Delay(20);	
		OLED_Set_Contrast(N);			
		}
	COLOR_SET(PADS_COLOR[5], 0);
	COLOR_SET(PADS_COLOR[5], 1);
	COLOR_SET(PADS_COLOR[5], 2);
	COLOR_SET(PADS_COLOR[5], 3);
	COLOR_SET(PADS_COLOR[5], 4);
	COLOR_SET(PADS_COLOR[5], 5);
	COLOR_SET(PADS_COLOR[5], 6);
	COLOR_SET(PADS_COLOR[5], 7);	
	HAL_SPI_Transmit_DMA(&hspi1, PAD_BUF, 100);		
	
	////////////////////////////mini SDRAM test
	#if defined(USART_STATUS_SENDER)		
	sprintf((char*)U_TX_DATA, "Mini SDRAM test\n\r");	
	HAL_UART_Transmit(&huart1, U_TX_DATA, 17, 5);	
	#endif	
	N = 0;	
	for(y=0;y<2046;y++)
		{
		PCM[y][993][0] = 0xFFAA;	
		}		
	for(y=0;y<2046;y++)
		{
		if(PCM[y][993][0] != 0xFFAA)	
			{	
			N++;
			}
		}	
	for(y=0;y<2046;y++)
		{
		PCM[y][7993][0] = 0xAA55;	
		}		
	for(y=0;y<2046;y++)
		{
		if(PCM[y][7993][0] != 0xAA55)	
			{	
			N++;
			}
		}	
	for(y=0;y<2046;y++)
		{
		PCM[y][3][1] = 0x0000;	
		}		
	for(y=0;y<2046;y++)
		{
		if(PCM[y][3][1] != 0x0000)	
			{	
			N++;
			}
		}	
	#if defined(USART_STATUS_SENDER)		
	sprintf((char*)U_TX_DATA, "%05lu errors\n\r", N);	
	HAL_UART_Transmit(&huart1, U_TX_DATA, 14, 25);		
	#endif			
	//#include "sdram_test.h"
	CLEAR_DB_VARIABLES();	
	OLED_CS1;	
	OLED_RAM_SELECT = OLED_WFM;	
	OLED_DrawFilledRectangle(0, 0, 128, 64, OLED_BLACK);
	OLED_DrawLine(63, 0, 63, 24, OLED_WHITE);	
	OLED_DrawLine(64, 0, 64, 24, OLED_WHITE);		
	sprintf((char*)Buf, "0:00.00");
	OLED_GotoXY(41, 30);
	OLED_Puts(Buf, &Font_7x10, OLED_WHITE);
	Buf[0] = 0x25; //% symbol	
	Buf[1] = 0;	
	OLED_GotoXY(123, 35);
	OLED_Puts(Buf, &Font_CDJ900, OLED_WHITE);	
	ShowTrackNumber(0);	
	DrawNewEmpty_TIMESCROLL();
	OLED_DrawLine(0, 27, 0, 38, OLED_WHITE);				///////////////////////
	OLED_DrawLine(17, 27, 17, 38, OLED_WHITE);			//	Track shield
	OLED_DrawLine(1, 26, 16, 26, OLED_WHITE);				//
	OLED_DrawLine(1, 39, 16, 39, OLED_WHITE);				///////////////////////
	OLED_UpdateScreen();	
	HAL_Delay(100);
	
  /* USER CODE END 2 */

  /* Infinite loop */
  /* USER CODE BEGIN WHILE */
 while (1)
  {
	if(SD_STATUS==SD_MOUNTED)				//////////////////////////////////////////////////////////////////////
		{
		wfmpos = play_adr/(294*wfmzoom);			
		if(previous_wfmpos != wfmpos)
			{
			OLED_RAM_SELECT = OLED_WFM;	
			previous_wfmpos = wfmpos;
			if(wfmzoom==1)
				{	
				wf_ofs = 0;
				}	
			else if(wfmzoom==2)
				{	
				wf_ofs = wfmx2;
				}
			else if(wfmzoom==4)
				{	
				wf_ofs = wfmx4;
				}
			else if(wfmzoom==8)
				{	
				wf_ofs = wfmx8;
				}
			else if(wfmzoom==16)
				{	
				wf_ofs = wfmx16;
				}
			else if(wfmzoom==32)
				{	
				wf_ofs = wfmx32;
				}
			a_div_v = (all_long/wfmzoom)+63;
			for(N=0;N<128;N++)
				{
				wpos = wfmpos+N;	
				if((wpos>=64) && (wpos<a_div_v))	
					{
					y = WFORMDYNAMIC[wf_ofs+wpos/2-32];	
					if(wpos%2==0)
						{
						y>>=4;		
						}						
					else
						{
						y&=0x0F;	
						}		
					if(N==63 || N==64)
						{
						if(y<11)
							{
							OLED_DrawLine(N, 0, N, 10-y, OLED_WHITE);	
							OLED_DrawLine(N, 12+y, N, 22, OLED_WHITE);	
							}				
						OLED_DrawLine(N, 11-y, N, 11+y, OLED_BLACK);	
						}				
					else
						{
						if(y<11)
							{	
							OLED_DrawLine(N, 0, N, 10-y, OLED_BLACK);	
							OLED_DrawLine(N, 12+y, N, 22, OLED_BLACK);	
							}
						OLED_DrawLine(N, 11-y, N, 11+y, OLED_WHITE);						
						}						
					}
				else			//pre start or end waveform	
					{
					if(N==63 || N==64)
						{
						OLED_DrawLine(N, 0, N, 22, OLED_WHITE);		
						}
					else
						{
						OLED_DrawLine(N, 0, N, 22, OLED_BLACK);	
						}					
					}	
				}	
			need_update_oled1|=0x1F;			//(0...4 = 5 lines)
			}	

		timepos = play_adr/588;			
		if(previous_timepos!= timepos)
			{
			OLED_RAM_SELECT = OLED_WFM;	
			previous_timepos = timepos;
			sprintf((char*)Buf, "%1lu:%02lu.%02lu", (play_adr/2646000)%10, (play_adr/44100)%60, (play_adr/588)%75);
			OLED_GotoXY(41, 30);
			OLED_Puts(Buf, &Font_7x10, OLED_WHITE);
			need_update_oled1|=0x18;			//(3...4)	
			REDRAW_TIMESCROLL((62*(play_adr/147))/all_long);	
			}
			
		if((4096*end_adr_valid_data)<(147*all_long))
			{
			res = f_read(&file, PCM[end_adr_valid_data][0], 32768, &nbytes);
			if(res==FR_OK)
				{
				RAMSCROLL((1727*end_adr_valid_data)/all_long);	
				end_adr_valid_data++;			
				}
			}	
						
		if(need_load_track)
			{				
			COLOR_SET(0, 0);
			COLOR_SET(0, 1);
			COLOR_SET(0, 2);
			COLOR_SET(0, 3);
			COLOR_SET(0, 4);
			COLOR_SET(0, 5);
			COLOR_SET(0, 6);
			COLOR_SET(0, 7);					
			HAL_SPI_Transmit_DMA(&hspi1, PAD_BUF, 100);
			HAL_Delay(100);
			PREPARE_LOAD_TRACK(track_play_now, TRACK_PLAY_IN_CURRENT_PLAYLIST);
			if(PADS_MODE==PADS_HCUE_REC)
				{
				PADS_MODE = PADS_HCUE;	
				}				
			previous_PADS_MODE = 0xFF; 		//forceble reload rgb leds	
			need_load_track = 0;		
			}
			
		if(HAL_GPIO_ReadPin(GPIOC, SW_CDSD_Pin)==1)
			{
			MOTOR_OFF;		
			}	
		else
			{
			MOTOR_ON;		
			}		
			
		if(HAL_GPIO_ReadPin(GPIOG, DOOR_Pin)==0)			//check sd card door now open
			{
			f_close(&file);	
			f_mount(0, "0", 0);					//unmount filesystem		
			TIM3->CCR1 = 0;		
			HAL_GPIO_WritePin(GPIOB, FLED_Pin, GPIO_PIN_RESET);
			MOTOR_OFF;	
			CLEAR_DB_VARIABLES();			
			OLED_RAM_SELECT = OLED_WFM;	
			OLED_DrawFilledRectangle(0, 0, 128, 25, OLED_BLACK);
			OLED_DrawLine(63, 0, 63, 24, OLED_WHITE);	
			OLED_DrawLine(64, 0, 64, 24, OLED_WHITE);			
			sprintf((char*)Buf, "0:00.00");
			OLED_GotoXY(41, 30);
			OLED_Puts(Buf, &Font_7x10, OLED_WHITE);
			ShowBPM(0xFFFF);	
			ShowTrackNumber(0);
			OLED_DrawFilledRectangle(0, 43, 127, 21, OLED_BLACK);	
			DrawNewEmpty_TIMESCROLL();
			need_update_oled1|=0xFF;			//all	
			COLOR_SET(PADS_COLOR[5], 0);
			COLOR_SET(PADS_COLOR[5], 1);
			COLOR_SET(PADS_COLOR[5], 2);
			COLOR_SET(PADS_COLOR[5], 3);
			COLOR_SET(PADS_COLOR[5], 4);
			COLOR_SET(PADS_COLOR[5], 5);
			COLOR_SET(PADS_COLOR[5], 6);
			COLOR_SET(PADS_COLOR[5], 7);	
			need_load_rgb = 1;
			SD_STATUS = SD_OPEN_DOOR;	
			dSHOW = 0xFF;
			SwitchInformationLayer(ROOT_DSPL);
			}
			
	/////////////////TEMPORARY			
	//	if((HAL_GetTick()-temp_time)>500)
	//		{
	//		sprintf((char*)U_TX_DATA, "%04lu.%04lu.%04lu.%04lu.%04lu", ADC_DATA[0], ADC_DATA[1], ADC_DATA[2], ADC_DATA[3], ADC_DATA[4]);
	//		U_TX_DATA[24] = 13;
	//		U_TX_DATA[25] = 10;	
	//		HAL_UART_Transmit(&huart1, U_TX_DATA, 26, 5);
	//		temp_time = HAL_GetTick();	
	//		}		
		}
	else if(SD_STATUS==SD_OPEN_DOOR)			//////////////////////////////////////////////////////////////////////
		{
		if(HAL_GPIO_ReadPin(GPIOG, DOOR_Pin)==1)			//check sd card door now close
			{
			HAL_GPIO_WritePin(GPIOB, FLED_Pin, GPIO_PIN_SET);
			SD_STATUS = SD_SCAN_RB;	
			}	
		}
	else if(SD_STATUS==SD_SCAN_RB)			//////////////////////////////////////////////////////////////////////
		{
		HAL_Delay(300);	
		BSP_SD_Init();	
		HAL_Delay(200);	
		CLEAR_DB_VARIABLES();
		res = f_mount(&FAT, "0", 1);
		if(res == FR_OK)
			{
			#if defined(USART_STATUS_SENDER)		
			sprintf((char*)U_TX_DATA, "Drive mounted\n\r");	
			HAL_UART_Transmit(&huart1, U_TX_DATA, 15, 5);	
			#endif		
				
			TOTAL_TRACKS = DATABASE_PARSER();
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

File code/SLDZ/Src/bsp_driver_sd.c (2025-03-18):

/**
 ******************************************************************************
  * @file    bsp_driver_sd.c for F4 (based on stm324x9i_eval_sd.c)
  * @brief   This file includes a generic uSD card driver.
  ******************************************************************************
  * This notice applies to any and all portions of this file
  * that are not between comment pairs USER CODE BEGIN and
  * USER CODE END. Other portions of this file, whether 
  * inserted by the user or by software development tools
  * are owned by their respective copyright owners.
  *
  * Copyright (c) 2024 STMicroelectronics International N.V. 
  * All rights reserved.
  *
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
  ******************************************************************************
  */
#define BUS_4BITS 1

#ifdef OLD_API
/* kept to avoid issue when migrating old projects. */
/* USER CODE BEGIN 0 */
/* Includes ------------------------------------------------------------------*/
#include "bsp_driver_sd.h"

/* Extern variables ---------------------------------------------------------*/ 
  
extern SD_HandleTypeDef hsd;
extern HAL_SD_CardInfoTypedef SDCardInfo; 

/**
  * @brief  Initializes the SD card device.
  * @retval SD status
  */
uint8_t BSP_SD_Init(void)
{
  uint8_t sd_state = MSD_OK;
  /* Check if the SD card is plugged in the slot */
  if (BSP_SD_IsDetected() != SD_PRESENT)
  {
    return MSD_ERROR;
  }
  /* HAL SD initialization */
  sd_state = HAL_SD_Init(&hsd, &SDCardInfo);
#ifdef BUS_4BITS
  /* Configure SD Bus width */
  if (sd_state == MSD_OK)
  {
    /* Enable wide operation */
    if (HAL_SD_WideBusOperation_Config(&hsd, SDIO_BUS_WIDE_4B) != SD_OK)
    {
      sd_state = MSD_ERROR;
    }
    else
    {
      sd_state = MSD_OK;
    }
  }
#endif
  return sd_state;
}

/**
  * @brief  Configures Interrupt mode for SD detection pin.
  * @retval Returns 0 in success otherwise 1. 
  */
uint8_t BSP_SD_ITConfig(void)
{  
  /* TBI: add user code here depending on the hardware configuration used */
  
  return (uint8_t)0;
}

/** @brief  SD detect IT treatment
  */
void BSP_SD_DetectIT(void)
{
  /* TBI: add user code here depending on the hardware configuration used */
}

/** @brief  SD detect IT detection callback
  */
__weak void BSP_SD_DetectCallback(void)
{
  /* NOTE: This function Should not be modified, when the callback is needed,
     the BSP_SD_DetectCallback could be implemented in the user file
  */ 
}

/**
  * @brief  Reads block(s) from a specified address in an SD card, in polling mode.
  * @param  pData: Pointer to the buffer that will contain the data to transmit
  * @param  ReadAddr: Address from where data is to be read  
  * @param  BlockSize: SD card data block size, that should be 512
  * @param  NumOfBlocks: Number of SD blocks to read 
  * @retval SD status
  */
uint8_t BSP_SD_ReadBlocks(uint32_t *pData, uint64_t ReadAddr, uint32_t BlockSize, uint32_t NumOfBlocks)
{
  uint8_t sd_state;
  if(HAL_SD_ReadBlocks(&hsd, pData, ReadAddr, BlockSize, NumOfBlocks) != SD_OK)
  {
    sd_state = MSD_ERROR;
  }
  else
  {
    sd_state = MSD_OK;
  }
  return sd_state;  
}

/**
  * @brief  Writes block(s) to a specified address in an SD card, in polling mode. 
  * @param  pData: Pointer to the buffer that will contain the data to transmit
  * @param  WriteAddr: Address from where data is to be written  
  * @param  BlockSize: SD card data block size, that should be 512
  * @param  NumOfBlocks: Number of SD blocks to write
  * @retval SD status
  */
uint8_t BSP_SD_WriteBlocks(uint32_t *pData, uint64_t WriteAddr, uint32_t BlockSize, uint32_t NumOfBlocks)
{
  uint8_t sd_state;
  if(HAL_SD_WriteBlocks(&hsd, pData, WriteAddr, BlockSize, NumOfBlocks) != SD_OK)  
  {
    sd_state = MSD_ERROR;
  }
  else
  {
    sd_state = MSD_OK;
  }
  return sd_state;  
}

/**
  * @brief  Reads block(s) from a specified address in an SD card, in DMA mode.
  * @param  pData: Pointer to the buffer that will contain the data to transmit
  * @param  ReadAddr: Address from where data is to be read  
  * @param  BlockSize: SD card data block size, that should be 512
  * @param  NumOfBlocks: Number of SD blocks to read 
  * @retval SD status
  */
uint8_t BSP_SD_ReadBlocks_DMA(uint32_t *pData, uint64_t ReadAddr, uint32_t BlockSize, uint32_t NumOfBlocks)
{
  uint8_t sd_state = MSD_OK;
  
  /* Read block(s) in DMA transfer mode */
  if(HAL_SD_ReadBlocks_DMA(&hsd, pData, ReadAddr, BlockSize, NumOfBlocks) != SD_OK)  
  {
    sd_state = MSD_ERROR;
  }
  
  /* Wait until transfer is complete */
  if(sd_state == MSD_OK)
  {
    if(HAL_SD_CheckReadOperation(&hsd, (uint32_t)SD_DATATIMEOUT) != SD_OK)  
    {
      sd_state = MSD_ERROR;
    }
    else
    {
      sd_state = MSD_OK;
    }
  }
  
  return sd_state; 
}

/**
  * @brief  Writes block(s) to a specified address in an SD card, in DMA mode.
  * @param  pData: Pointer to the buffer that will contain the data to transmit
  * @param  WriteAddr: Address from where data is to be written  
  * @param  BlockSize: SD card data block size, that should be 512
  * @param  NumOfBlocks: Number of SD blocks to write 
  * @retval SD status
  */
uint8_t BSP_SD_WriteBlocks_DMA(uint32_t *pData, uint64_t WriteAddr, uint32_t BlockSize, uint32_t NumOfBlocks)
{
  uint8_t sd_state = MSD_OK;
  
  /* Write block(s) in DMA transfer mode */
  if(HAL_SD_WriteBlocks_DMA(&hsd, pData, WriteAddr, BlockSize, NumOfBlocks) != SD_OK)  
  {
    sd_state = MSD_ERROR;
  }
  
  /* Wait until transfer is complete */
  if(sd_state == MSD_OK)
  {
    if(HAL_SD_CheckWriteOperation(&hsd, (uint32_t)SD_DATATIMEOUT) != SD_OK)  
    {
      sd_state = MSD_ERROR;
    }
    else
    {
      sd_state = MSD_OK;
    }
  }
  
  return sd_state; 
}

/**
  * @brief  Erases the specified memory area of the given SD card. 
  * @param  StartAddr: Start byte address
  * @param  EndAddr: End byte address
  * @retval SD status
  */
uint8_t BSP_SD_Erase(uint64_t StartAddr, uint64_t EndAddr)
{
  uint8_t sd_state;
  if(HAL_SD_Erase(&hsd, StartAddr, EndAddr) != SD_OK)  
  {
    sd_state = MSD_ERROR;
  }
  else
  {
    sd_state = MSD_OK;
  }
  return sd_state;
}

/**
  * @brief  Handles SD card interrupt request.
  */
void BSP_SD_IRQHandler(void)
{
  HAL_SD_IRQHandler(&hsd);
}

/**
  * @brief  Handles SD DMA Tx transfer interrupt request.
  */
void BSP_SD_DMA_Tx_IRQHandler(void)
{
  HAL_DMA_IRQHandler(hsd.hdmatx); 
}

/**
  * @brief  Handles SD DMA Rx transfer interrupt request.
  */
void BSP_SD_DMA_Rx_IRQHandler(void)
{
  HAL_DMA_IRQHandler(hsd.hdmarx);
}

/**
  * @brief  Gets the current SD card data status.
  * @retval Data transfer state.
  *          This value can be one of the following values:
  *            @arg  SD_TRANSFER_OK: No data transfer is acting
  *            @arg  SD_TRANSFER_BUSY: Data transfer is acting
  *            @arg  SD_TRANSFER_ERROR: Data transfer error 
  */
HAL_SD_TransferStateTypedef BSP_SD_GetStatus(void)
{
  return(HAL_SD_GetStatus(&hsd));
}
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

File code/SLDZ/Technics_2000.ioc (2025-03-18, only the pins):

Mcu.UserName=STM32F429ZITx
PA0/WKUP.Signal=ADCx_IN0
PA1.Signal=ADCx_IN1
PA10.Signal=USART1_RX
PA11.GPIO_Label=TT_REV
PA11.Signal=GPIO_Output
PA12.GPIO_Label=FREE
PA12.Signal=GPIO_Output
PA15.Signal=I2S3_WS
PA2.Signal=ADCx_IN2
PA3.Signal=ADCx_IN3
PA4.Signal=ADCx_IN4
PA5.Signal=SPI1_SCK
PA7.Signal=SPI1_MOSI
PA8.GPIO_Label=TT_ON
PA8.Signal=GPIO_Output
PA9.Signal=USART1_TX
PB0.GPIO_Label=TIMCODE_A
PB0.Signal=GPXTI0
PB10.Signal=SPI2_SCK
PB12.GPIO_Label=CS0
PB12.Signal=GPIO_Output
PB13.GPIO_Label=CS1
PB13.Signal=GPIO_Output
PB14.GPIO_Label=DC
PB14.Signal=GPIO_Output
PB15.Signal=SPI2_MOSI
PB3.Signal=I2S3_CK
PB4.Signal=S_TIM3_CH1
PB5.Signal=FMC_SDCKE1
PB6.Signal=FMC_SDNE1
PB8.GPIO_Label=FLED
PB8.Signal=GPIO_Output
PB9.GPIO_Label=SD_EN
PB9.Signal=GPIO_Input
PC0.Signal=FMC_SDNWE
PC10.Signal=SDIO_D2
PC11.Signal=SDIO_D3
PC12.Signal=SDIO_CK
PC14/OSC32_IN.GPIO_Label=SW_CDSD
PC14/OSC32_IN.Signal=GPIO_Input
PC15/OSC32_OUT.GPIO_Label=SW_REV
PC15/OSC32_OUT.Signal=GPIO_Input
PC6.Signal=S_TIM8_CH1
PC7.Signal=I2S3_MCK
PC8.Signal=SDIO_D0
PC9.Signal=SDIO_D1
PD0.Signal=FMC_D2_DA2
PD1.Signal=FMC_D3_DA3
PD10.Signal=FMC_D15_DA15
PD11.GPIO_Label=RST
PD11.Signal=GPIO_Output
PD12.Signal=S_TIM4_CH1
PD13.GPIO_Label=TIMCODE_B
PD13.Signal=GPIO_Input
PD14.Signal=FMC_D0_DA0
PD15.Signal=FMC_D1_DA1
PD2.Signal=SDIO_CMD
PD6.Signal=I2S3_SD
PD8.Signal=FMC_D13_DA13
PD9.Signal=FMC_D14_DA14
PE0.Signal=FMC_NBL0
PE1.Signal=FMC_NBL1
PE10.Signal=FMC_D7_DA7
PE11.Signal=FMC_D8_DA8
PE12.Signal=FMC_D9_DA9
PE13.Signal=FMC_D10_DA10
PE14.Signal=FMC_D11_DA11
PE15.Signal=FMC_D12_DA12
PE2.GPIO_Label=ENC_A
PE2.Signal=GPXTI2
PE3.GPIO_Label=ENC_B
PE3.Signal=GPIO_Input
PE4.GPIO_Label=DATA_LED
PE4.Signal=GPIO_Output
PE5.GPIO_Label=CLK_LED
PE5.Signal=GPIO_Output
PE7.Signal=FMC_D4_DA4
PE8.Signal=FMC_D5_DA5
PE9.Signal=FMC_D6_DA6
PF0.Signal=FMC_A0
PF1.Signal=FMC_A1
PF11.Signal=FMC_SDNRAS
PF12.Signal=FMC_A6
PF13.Signal=FMC_A7
PF14.Signal=FMC_A8
PF15.Signal=FMC_A9
PF2.Signal=FMC_A2
PF3.Signal=FMC_A3
PF4.Signal=FMC_A4
PF5.Signal=FMC_A5
PF7.Signal=SPI5_SCK
PF8.GPIO_Label=SPI5_CS
PF8.Signal=GPIO_Output
PF9.Signal=SPI5_MOSI
PG0.Signal=FMC_A10
PG1.Signal=FMC_A11
PG10.GPIO_Label=MUTE
PG10.Signal=GPIO_Output
PG12.GPIO_Label=DOOR
PG12.Signal=GPIO_Input
PG15.Signal=FMC_SDNCAS
PG2.Signal=FMC_A12
PG4.Signal=FMC_A14_BA0
PG5.Signal=FMC_A15_BA1
PG6.GPIO_Label=SW_TTCD
PG6.Signal=GPIO_Input
PG8.Signal=FMC_SDCLK
PH0/OSC_IN.Signal=RCC_OSC_IN
PH1/OSC_OUT.Signal=RCC_OSC_OUT

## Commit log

2025-03-18 3d printing files
    [Roller Holder.FCStd]
2025-03-18 task files for cnc machine
    [CUT.dwg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]
2025-03-18 Kicad 5.1.10

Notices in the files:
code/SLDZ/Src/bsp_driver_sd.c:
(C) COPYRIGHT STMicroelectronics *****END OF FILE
